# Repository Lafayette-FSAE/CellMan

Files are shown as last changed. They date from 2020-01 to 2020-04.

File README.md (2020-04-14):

# CellMan v2.2
A Cell Management Board for the Lafayette FSAE Accumulator Management System.

The purpose of CellMan is twofold. First, it is responsible for making and reporting
key measurements of the Cell it is mounted to. The most important of these are Voltage 
and Temperature, which are used by PacMan to determine if a fault condition has occured, and can also be used to help estimate State of Charge.
In addition, CellMan is capable of measuring the voltage of its Cell's negative terminal relative to the segment, used for determining its position, 
and some properties of its balancing circuit.

Render of CellMan

Each CellMan has also been equipped with an experimental Balancing Circuit, which can be used to allow active balancing of Cells within the same segment.
This is done through an isolated flyback converter, which pulls current from the cell it sits on, steps it up to the full segment voltage through an isolated
transformer, and outputs it back to the segment. A CellMan is capable of measuring the current being drawn from the cell by the flyback converter and the
voltage on its output side, and can report these back to PacMan along with the measurements mentioned above.

## Interface

Each CellMan is an I2C slave device, and can be controlled by a master, usually PacMan. All data reported to PacMan is sent over this interface, as well as commands
that control the high level behavior of CellMan.

While CellMan on different segments are electrically isolated from eachother, they occupy the same I2C bus, through 2 isolators on the PacMan board, and so their
addresses cannot conflict

### Reading Data

When data is requested from CellMan, it will report it over the bus, one byte at a time,  and always in the same order. An arbitrary number of bytes can be requested.

Most data is stored as 16 bit integers, and so is sent in 2 byte pairs, with the Least Significant Byte first, and the Most Significant Byte second.

Bytes are sent in the following order:

|Byte|0 |1 |2 |3 |4 |5 |6 |
|----|---|---|---|---|---|---|---|
|Data|Firmware Version|Cell Voltage LSB|Cell Voltage MSB|Temperature LSB|Temperature MSB|Position LSB |Position MSB |
|Unit|NA |mV |mV |1/10 ºC |1/10 ºC |Raw ADC Value|Raw ADC Value|

Additional data can be added to the end of this as needed.

### Sending Commands

PacMan is controlled by writing data to one or more 16 bit registers. Each write command should be 3 bytes long, a 1 byte address, followed by 2 bytes of data.

Register addresses are organized as follows:

#### Calibration Parameters

While this feature is not currently supported, CellMan will eventually allow configuration of its many calibration functions for maximum accuracy.
Addresses from 0x01 to 0x0F have been reserved for this purpose.

|Address|Description |
|---|---|
|0x01 |Temp Slope |
|0x02 |Temp Offset |
|0x03 |Balance Current Slope|
|0x04 |Balance Voltage Slope|

#### Balance Circuit

Addresses from 0x11 to 0x1F are reserved for registers which control the behavior of the Balance Circuit.
Currently, the circuit can be enabled or disabled, and the duty cycle and frequency of its control signal
can be changed.
0x14 is reserved for a Target Voltage parameter in order to allow support for a closed loop control scheme
to be used in the future. 

|Address|Description |
|---|---|
|0x11 |Balance Enabled  |
|0x12 |Balance Duty Cycle|
|0x13 |Balance Frequency|
|0x14 |Target Voltage |

#### Debug

0x23 controls the board's green LED, used for Debugging and feedback.

|Address|Description |
|---|---|
|0x23 |Debug LED |

## Schematic
[Link to PDF](https://sites.lafayette.edu/motorsports/files/2019/11/CellMan.pdf)

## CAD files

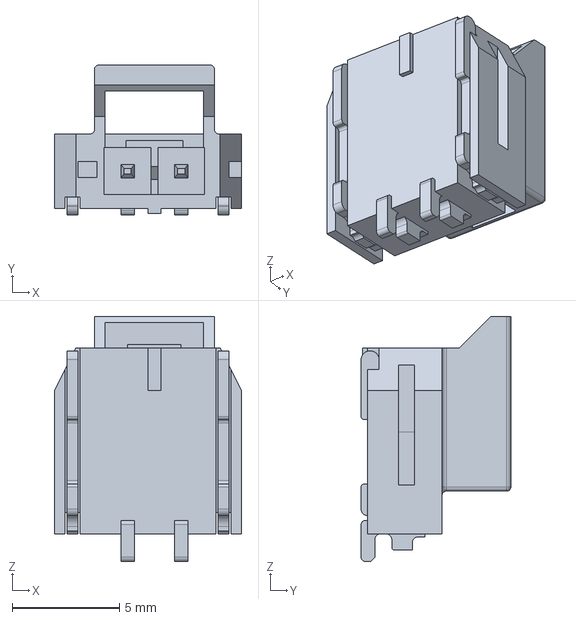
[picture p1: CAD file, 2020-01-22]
3d-Models/1054301102.stp
8.74 x 6.99 x 11.4 mm

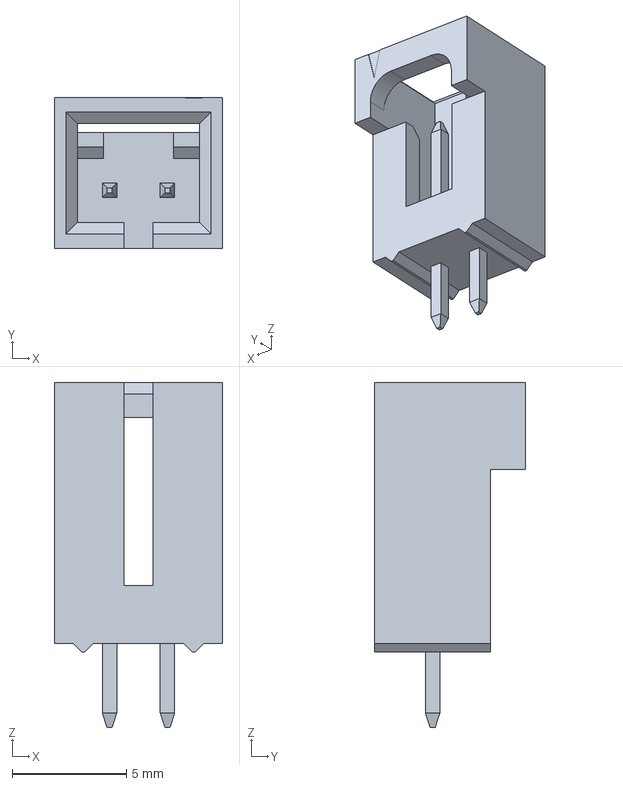
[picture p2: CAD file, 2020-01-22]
3d-Models/705430001.stp
7.37 x 6.60 x 15.1 mm

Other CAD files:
3d-Models/2018Parts/batteryCell.ipt
3d-Models/2018Parts/batteryCellTop.ipt
3d-Models/2018Parts/parameters_metric.ipt
3d-Models/Cell_Mounting.ipt
3d-Models/batteryCellAssembly.iam

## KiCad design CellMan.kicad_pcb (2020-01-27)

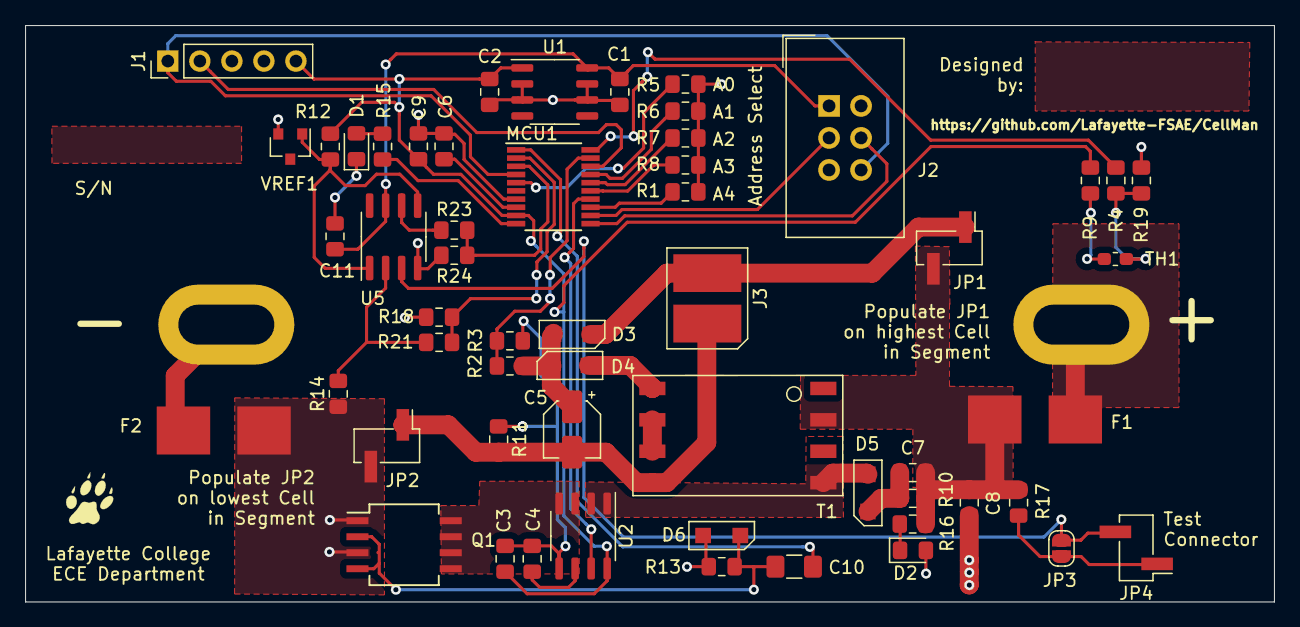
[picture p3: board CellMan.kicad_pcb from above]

Board: 2 copper layers, 99.1 x 45.7 mm, 58 parts (0 on the bottom side), 43 nets.

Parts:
BT1: Battery_Cell; CELL60AH
C1: 0.33uF; C_0805_2012Metric_Pad1.15x1.40mm_HandSolder
C2, C3, C11: 0.1uF; C_0805_2012Metric_Pad1.15x1.40mm_HandSolder
C4: 1nF; C_0805_2012Metric_Pad1.15x1.40mm_HandSolder
C5: 1uF 50V; CP_Elec_4x5.4
C6, C8, C9: 1uF; C_0805_2012Metric_Pad1.15x1.40mm_HandSolder
C7: C; C_0805_2012Metric_Pad1.15x1.40mm_HandSolder
C10: 0.1uF 250V; C_1206_3216Metric_Pad1.42x1.75mm_HandSolder
D1: LED_Green; LED_0805_2012Metric_Pad1.15x1.40mm_HandSolder
D2: LED_Red; LED_0805_2012Metric_Pad1.15x1.40mm_HandSolder
D3, D4, D5, D6: 60V 2A; Diode_NTS260ESF
F1, F2: LittelfuseHolder; fuse_holder_smd_littelfuse
J1: Conn_01x05_Male; PinHeader_1x05_P2.54mm_Vertical
J2: IDC-Connector; IDC-Header_2x03_P2.54mm_Vertical
J3: AVX-IDC; AVX
JP1, JP2, JP4: Jumper; PinHeader_1x02_P2.54mm_Vertical_SMD_Pin1Left
JP3: SolderJumper_2_Open; SolderJumper-2_P1.3mm_Open_RoundedPad1.0x1.5mm
LOGO2: LeopardPawLogo; Paw
MCU1: STM8S003F3; TSSOP-20_4.4x6.5mm_P0.65mm
Q1: SP8K24FRATB; SO-8_5.3x6.2mm_P1.27mm
R1, R2, R3, R5, R6, R7, R8, R9, R10, R11, R12, R13, R15, R19: R; R_0805_2012Metric_Pad1.15x1.40mm_HandSolder
R4: 410; R_0805_2012Metric_Pad1.15x1.40mm_HandSolder
R14, R17, R23, R24: 2k; R_0805_2012Metric_Pad1.15x1.40mm_HandSolder
R16: 250; R_0805_2012Metric_Pad1.15x1.40mm_HandSolder
R18: 10k; R_0805_2012Metric_Pad1.15x1.40mm_HandSolder
R21: 51k; R_0805_2012Metric_Pad1.15x1.40mm_HandSolder
T1: FlybackTransformer; Transformer
TH1: NTCS0603; R_0603_1608Metric_Pad1.05x0.95mm_HandSolder
U1: L78L05CD13TR; SO-8_3.9x4.9mm_P1.27mm
U2: ACHS-7122; SO-8_3.9x4.9mm_P1.27mm
U5: AD8479; SOIC-8_3.9x4.9mm_P1.27mm
VREF1: ADR510; SOT-23

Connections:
+5V: C2.1, C9.1, J1.5, MCU1.9, R9.2, R12.1, U1.1, U2.8
+9V: C1.1, C11.1, J2.1, U1.8, U5.7
/A0: MCU1.5, R5.1
/A1: MCU1.17, R6.1
/A2: MCU1.16, R7.1
/A3: MCU1.15, R8.2
/A4: MCU1.13, R1.2
/Balance+: D3.1, J3.2, JP1.1
/Balance-: C5.2, J3.1, JP2.1, R11.2, T1.5
/Balance_ctl: C10.2, MCU1.1
/Balance_current: MCU1.14, U2.7
/Balance_feedback: MCU1.19, R2.2, R3.1
/Cell+: C7.1, C8.1, F1.1, JP1.2, R10.1, R16.1, R17.1, T1.2
/Cell+(RAW): BT1.1, F1.2
/Cell-: C8.2, D2.2, D6.2, F2.1, JP2.2, Q1.1, Q1.3, R13.2, R14.1
/Cell-(RAW): BT1.2, F2.2
/CellBalancing/Filter: C4.1, U2.6
/CellBalancing/LocalVout: C5.1, D3.2, D4.1, R2.1
/CellBalancing/ThisNetNeedsAName: Q1.5, Q1.6, Q1.7, Q1.8, U2.3, U2.4
/CellBalancing/ThisOneToo: D5.2, T1.4, U2.1, U2.2
/CellMeasurement/CellVoltage_RAW: R23.1, U5.6
/CellMeasurement/Vref: R12.2, U5.1, U5.5, VREF1.1
/CellTemp: MCU1.20, R4.1
/CellVoltage: MCU1.3, R23.2, R24.1
/DividedCell-: MCU1.2, R18.1, R21.2
/Ref_Cap: C6.2, MCU1.8
/Reset: J1.1, J2.6, MCU1.4
/SCL: J2.3, MCU1.12
/SDA: J2.4, MCU1.11
/SWIM: J1.2, MCU1.18
/User_LED: MCU1.10, R15.1
GND: C1.2, C2.2, C3.2, C4.2, C6.1, C9.2, C11.2, D1.1, J1.3, J2.2, J2.5, MCU1.7, R1.1, R3.2, R5.2, R6.2, R7.2, R8.1, R11.1, R19.1, R24.2, U1.2, U1.3, U1.6, U1.7, U2.5, U5.4, VREF1.2
unnamed: C7.2, D5.1, R10.2
unnamed: C10.1, D6.1, Q1.2, Q1.4, R13.1
unnamed: D1.2, R15.2
unnamed: D2.1, R16.2
unnamed: D4.2, T1.8
unnamed: JP3.1, JP4.1, R17.2
unnamed: JP3.2, JP4.2, U5.3
unnamed: R9.1, TH1.1
unnamed: R14.2, R21.1, U5.2
unnamed: R4.2, R19.2, TH1.2
unnamed: T1.6, T1.7

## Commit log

2019-09-21 Added Project to Git
    [CellMan.kicad_pcb, CellMan.sch]
2019-09-21 Added Power and GND symbols to ADC Address Select
    [CellMan.sch]
2019-09-21 Added Datasheets to I2C symbols
    [CellMan.sch]
2019-09-24 Changed IO expander and added Reverse Polarity Protection
    [CellMan.sch]
2019-09-24 Added some indicators and Debugging Pins
    [CellMan.sch]
2019-09-24 Updated Cell Voltage Measurement
    [CellMan.sch]
2019-09-25 Added bypass capacitors to Power in and power out ports
    [CellMan.sch]
2019-09-25 Changed GND net names
    [CellMan.sch]
2019-09-27 finished adding diff amp
    [CellMan.sch, voltage_measurement.sch]
2019-10-02 started PCB layout
    [CellMan.kicad_pcb, CellMan.sch, Cell_Mounting.0001.ipt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]
2019-10-03 continued work on layout
    [CellMan.kicad_pcb]
2019-10-04 layout continues
    [CellMan.kicad_pcb, CellMan.sch]
2019-10-04 finished placing components
    [CellMan.kicad_pcb, CellMan.sch]
2019-10-05 made mounting holes bigger
    [CellMan.kicad_pcb, CellMan.sch]
2019-10-06 fixed dip switch package
    [CellMan.kicad_pcb, CellMan.sch]
2019-10-08 layed out some more traces
    [CellMan.kicad_pcb, CellMan.sch]
2019-10-09 Routed more traces
    [CellMan.kicad_pcb, CellMan.sch, voltage_measurement.sch]
2019-10-09 Ask Jon
    [CellMan.kicad_pcb]
2019-10-09 fixed ground plane issue
    [CellMan.kicad_pcb, CellMan.sch, voltage_measurement.sch]
2019-10-09 added cutout in ground plane for safecellminus
    [CellMan.kicad_pcb]
2019-10-09 something minor
    [CellMan.kicad_pcb]
2019-10-09 zero unrouted traces baby
    [CellMan.kicad_pcb, CellMan.sch, voltage_measurement.sch]
2019-10-15 Reviewed board, 10 unrouted traces to go
    [CellMan-B_Cu.gbr, CellMan-B_Mask.gbr, CellMan-B_Paste.gbr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]
2019-10-16 Fixed some problems
    [CellMan.kicad_pcb]
2019-10-16 Fixed Temp Sensor Footprint
    [CellMan.sch]
2019-10-18 added solder mask for serial number
    [CellMan.kicad_pcb]
2019-10-18 made dimensions even
    [CellMan.kicad_pcb, CellMan.sch]
2019-10-24 archived version 0
    [CellMan.sch]
2019-10-25 dropped some dead weight
    [CellMan-B_Cu.gbr, CellMan-B_Mask.gbr, CellMan-B_Paste.gbr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]
2019-10-27 Started work on post-design review version
    [CellMan.kicad_pcb, CellMan.sch, voltage_measurement.sch]
2019-10-28 Zero unrouted traces baby! Wait, where have I heard that before?
    [CellMan.kicad_pcb, CellMan.sch, voltage_measurement.sch]
2019-10-28 adjusted mounting and added flair
    [CellMan.kicad_pcb]
2019-10-29 switched power supply to 24V (Seg+) and removed ADC
    [CellMan.kicad_pcb, CellMan.sch, voltage_measurement.sch]
2019-11-01 idk, theres ovals now
    [CellMan.kicad_pcb, CellMan.sch, voltage_measurement.sch]
2019-11-01 KiCad says there are no more traces to route, but my heart says otherwise
    [CellMan.kicad_pcb, CellMan.sch]
2019-11-04 some cleaning up
    [CellMan.kicad_pcb, CellMan.sch, voltage_measurement.sch]
2019-11-05 removed dip switch
    [CellMan.kicad_pcb, CellMan.sch, CellMan_bom_1.xlsx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]
2019-11-05 removed discrete divider circuitry
    [voltage_measurement.sch]
2019-11-05 Replaced discrete voltage divider and diff amp with AD8479
    [CellMan.kicad_pcb, voltage_measurement.sch]
2019-11-06 cosmetic things
    [CellMan-B_Cu.gbr, CellMan-B_Mask.gbr, CellMan-B_SilkS.gbr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]
2019-11-06 switched to 5V regulator
    [CellMan.sch, CellMan.step, CellMan_bom_1.xlsx]
2019-11-07 cleaned up schematic a bit
    [CellMan.kicad_pcb, CellMan.sch, voltage_measurement.sch]
2019-11-12 Replaced generic parts with parts in our custom library
    [CellMan.sch]
2019-11-18 cleaned up schematic
    [CellMan.sch]
2020-01-09 last commit
    [CellMan.sch]
2020-01-09 drew draft of schematic
    [CellMan.sch]
2020-01-10 Update to top level schematic
    [CellBalancing.sch, CellMan.sch, CellMeasurement.sch]
2020-01-10 More detailed Balance Circuit with specific parts
    [CellBalancing.sch, CellMeasurement.sch]
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2020-01-10 Assigned footprints to symbols
    [CellBalancing.sch, CellMan.sch, CellMeasurement.sch]
2020-01-11 Rearranged components to make more room for flyback converter
    [CellBalancing.sch, CellMan.kicad_pcb, CellMan.sch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]
2020-01-11 Board Layout and routing
    [CellBalancing.sch, CellMan.kicad_pcb, CellMan.sch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]
2020-01-11 Cleaned up silkscreen
    [CellMan.kicad_pcb]
2020-01-11 Updated Version Numbers
    [CellBalancing.sch, CellMan.kicad_pcb, CellMan.sch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]
2020-01-19 Cell Balancing
    [CellBalancing.sch, CellMan.sch, CellMeasurement.sch]
2020-01-19 Updated Schematic
    [CellBalancing.sch, CellMan.kicad_pcb, CellMan.sch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]
2020-01-19 Start of new layout
    [CellMan.kicad_pcb, CellMan.sch, CellMeasurement.sch]
2020-01-19 WIP 1/19
    [CellMan.kicad_pcb]
2020-01-21 9 Unrouted Traces?
    [CellBalancing.sch, CellMan.kicad_pcb, CellMan.sch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]
2020-01-21 Version 2.2 Review
    [CellBalancing.sch, CellMan.sch, CellMeasurement.sch]
2020-01-22 Who Cares
    [1054301102.stp, 705430001.stp, CellBalancing.sch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]
2020-01-23 Traces Routed
    [CellMan.kicad_pcb]
2020-01-23 Added Flair
    [CellMan.kicad_pcb]
2020-01-23 Removed Extra Mounting Holes
    [CellBalancing.sch, CellMan.kicad_pcb, CellMan.sch]
2020-01-23 Aesthetic changes
    [CellMan.kicad_pcb]
2020-01-23 More Tweaks
    [CellBalancing.sch, CellMan.kicad_pcb, CellMan.sch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]
2020-01-24 Ready for spin
    [CellBalancing.sch, CellMan.kicad_pcb, CellMan.sch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]
2020-01-27 Updated BOM
    [CellBalancing.sch, CellMan.kicad_pcb, CellMan.sch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]
2020-02-04 Updated Gerbers
    [CellMan-B_Cu.gbr, CellMan-B_Mask.gbr, CellMan-B_SilkS.gbr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]
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
